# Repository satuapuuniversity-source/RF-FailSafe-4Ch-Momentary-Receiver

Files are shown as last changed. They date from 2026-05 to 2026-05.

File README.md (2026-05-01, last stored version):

This project is a smart RF receiver board made for things like quiz buzzers, remote switches, or simple automation systems.

Normally, RF receivers can have a problem:
👉 if the signal suddenly stops, the output can get “stuck” ON.
That’s bad, especially in real applications.

So I fixed that.

This board uses a small logic chip (74HC08) to make sure:
✔ the output turns ON only when a signal is actually present
✔ and turns OFF instantly when the signal is gone

So everything works clean and momentary—just like pressing a button.

Another cool thing is the RCA outputs.
They work like simple switches (dry contact), not powered outputs.

👉 That means you can safely connect this board to other systems without worrying about voltage mismatch.

Each channel also has:
💡 a small LED
🔁 a sensing loop (10k resistor)

So you can see if your external device is connected and working. Super helpful during setup.

For power, it runs on a single 18650 battery, and a boost converter keeps everything stable at 5V.
So it’s portable and reliable.

And the PCB?
Designed in KiCad with clear labels, so it’s easy to install and use, even if you're not an expert.

👉 In short:
This is a safe, reliable, no-glitch RF receiver that behaves exactly how you expect—no stuck signals, no confusion.

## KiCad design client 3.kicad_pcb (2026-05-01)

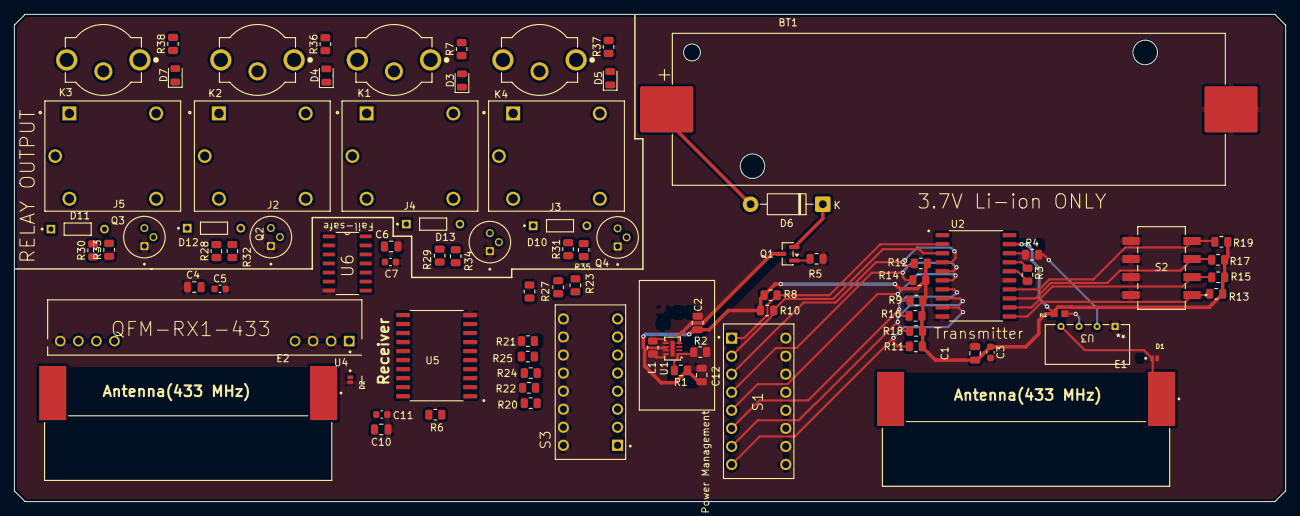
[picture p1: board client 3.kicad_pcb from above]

Board: 2 copper layers, 178.8 x 68.5 mm, 86 parts (0 on the bottom side), 67 nets.

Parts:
BT1: Battery_Cell; BatteryHolder_Keystone_1042_1x18650
C1, C4, C6, C10: 10uF; C_0805_2012Metric
C2, C12: 10u; C_0805_2012Metric
C3, C5, C7, C11: 0.1u; C_0603_1608Metric
D1, D2: PESD5V0S1UL_315; DIO_PESD5V0S1UL_315
D3, D4, D5, D7: LED; LED_0805_2012Metric
D6: 1N4007; D_DO-41_SOD81_P10.16mm_Horizontal
D10, D11, D12, D13: 1N4148; DIOAD753W49L380D172B
E1, E2: ANT-433-HESM; XDCR_ANT-433-HESM
FL1: BLM18PG121SN1D; BEADC1608X95N
J2, J3, J4, J5: RCJ-023; CUI_RCJ-023
K1, K2, K3, K4: SRD-05VDC-SL-C; RELAY_SRD-05VDC-SL-C
L1: 4.7u; R_0805_2012Metric
Q1: SI2301CDS-T1-E3; SOT-23
Q2, Q3, Q4, Q5: 2N2222A; TO127P584H533-3
R1: 976K; R_0805_2012Metric
R2: 309K; R_0805_2012Metric
R3: 1M; R_0805_2012Metric
R4, R32, R33, R34, R35: 1k; R_0805_2012Metric
R5: 100k; R_0805_2012Metric
R6: 51k; R_0805_2012Metric
R7, R8, R9, R10, R11, R12, R13, R14, R15, R16, R17, R18, R19, R20, R21, R22, R23, R24, R25, R26, R27, R28, R29, R30, R31, R36, R37, R38: 10k; R_0805_2012Metric
S1, S3: DS01C-254-L-08BE; SW_DS01C-254-L-08BE
S2: 219-4MST; SW_219-4MST
U1: MCP1640T-I/MC; DFN-8-1EP_2x3mm_P0.5mm_EP0.61x2.2mm
U2: HT12E-20SOP; SOP127P1032X264-20N
U3: QAM-TX2-433; QAM-TX2-433_RFS
U4: QFM-RX1-433; MODULE_QFM-RX1-433
U5: HT12D; SOP127P1032X264-20N
U6: 74HC08D_653; SOIC127P600X175-14N

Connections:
+5V: C1.1, C2.1, C3.1, C4.1, C5.1, C6.1, C7.1, C10.1, C11.1, C12.1, D10.K, D11.K, D12.K, D13.K, FL1.1, K1.A1, K2.A1, K3.A1, K4.A1, R1.1, R8.2, R9.2, R10.2, R11.2, R12.2, R13.2, R14.2, R15.2, R16.2, R17.2, R18.2, R19.2, R20.2, R21.2, R22.2, R23.2, R24.2, R25.2, R26.2, R27.2, R28.2, R29.2, R30.2, R31.2, U1.6 (VOUTP), U1.7 (VOUTS), U2.19 (VDD), U4.4 (SUPPLY_VOLTAGE), U4.5 (SUPPLY_VOLTAGE), U5.19 (VDD), U6.14 (VCC)
/Receiver/Relay_Ch1: R28.1, R32.1, U6.3 (1Y)
/Receiver/Relay_Ch2: R31.1, R35.1, U6.6 (2Y)
/Receiver/Relay_Ch3: R29.1, R34.1, U6.8 (3Y)
/Receiver/Relay_Ch4: R30.1, R33.1, U6.11 (4Y)
GND: BT1.2 (-), C1.2, C2.2, C3.2, C4.2, C5.2, C6.2, C7.2, C10.2, C11.2, C12.2, D1.A, D2.A, Q2.1, Q3.1, Q4.1, Q5.1, R2.2, R5.2, S1.1B, S1.2B, S1.3B, S1.4B, S1.5B, S1.6B, S1.7B, S1.8B, S2.5, S2.6, S2.7, S2.8, S3.1B, S3.2B, S3.3B, S3.4B, S3.5B, S3.6B, S3.7B, S3.8B, U1.2 (SGND), U1.3 (PGND), U1.9 (EP), U2.10 (VSS), U2.15 (~TE), U3.1 (GND), U4.2 (GROUND), U4.3 (GROUND), U4.8 (GROUND), U5.10 (VSS), U6.7 (GND)
unnamed: BT1.1 (+), D6.2 (A)
unnamed: D3.2 (A), R7.1
unnamed: D3.1 (K), J4.2, K1.NO
unnamed: D4.2 (A), R36.1
unnamed: D4.1 (K), J2.2, K2.NO
unnamed: D5.2 (A), R37.1
unnamed: D5.1 (K), J3.2, K4.NO
unnamed: D6.1 (K), Q1.2 (S)
unnamed: D7.2 (A), R38.1
unnamed: D7.1 (K), J5.2, K3.NO
unnamed: D10.A, K4.A2, Q4.3
unnamed: D11.A, K3.A2, Q3.3
unnamed: D12.A, K2.A2, Q2.3
unnamed: D13.A, K1.A2, Q5.3
unnamed: J2.1A (1), J2.1B (1), K2.COM, R36.2
unnamed: J3.1A (1), J3.1B (1), K4.COM, R37.2
unnamed: J4.1A (1), J4.1B (1), K1.COM, R7.2
unnamed: J5.1A (1), J5.1B (1), K3.COM, R38.2
unnamed: L1.1, Q1.3 (D), U1.4 (EN), U1.8 (VIN)
unnamed: Q1.1 (G), R5.1
unnamed: Q2.2, R32.2
unnamed: Q3.2, R33.2
unnamed: Q4.2, R35.2
unnamed: Q5.2, R34.2
unnamed: L1.2, U1.5 (SW)
unnamed: R1.2, R2.1, U1.1 (VFB)
unnamed: R8.1, S1.1A, U2.2 (A0)
unnamed: R10.1, S1.2A, U2.3 (A1)
unnamed: R12.1, S1.3A, U2.4 (A2)
unnamed: R14.1, S1.4A, U2.5 (A3)
unnamed: R9.1, S1.5A, U2.6 (A4)
unnamed: R16.1, S1.6A, U2.7 (A5)
unnamed: R18.1, S1.7A, U2.8 (A6)
unnamed: R11.1, S1.8A, U2.9 (A7)
unnamed: R13.1, S2.1, U2.11 (AD8)
unnamed: R15.1, S2.2, U2.12 (AD9)
unnamed: R17.1, S2.3, U2.13 (AD10)
unnamed: R19.1, S2.4, U2.14 (AD11)
unnamed: R4.1, U2.18 (DOUT)
unnamed: R3.1, U2.17 (OSC1)
unnamed: R3.2, U2.16 (OSC2)
unnamed: D1.K, E1.1, U3.4 (ANT)
unnamed: R4.2, U3.2 (IN)
unnamed: FL1.2, U3.3 (VCC)
unnamed: U4.7 (DATA_INPUT), U5.15 (DIN)
unnamed: D2.K, E2.1, U4.1 (EXTERNAL_ANTENNA)
unnamed: R20.1, S3.1A, U5.2 (A0)
unnamed: R22.1, S3.2A, U5.3 (A1)
unnamed: R24.1, S3.3A, U5.4 (A2)
unnamed: R25.1, S3.4A, U5.5 (A3)
unnamed: R21.1, S3.5A, U5.6 (A4)
unnamed: R26.1, S3.6A, U5.7 (A5)
unnamed: R27.1, S3.7A, U5.8 (A6)
unnamed: R23.1, S3.8A, U5.9 (A7)
unnamed: U5.11 (D8), U6.1 (1A)
unnamed: U5.12 (D9), U6.4 (2A)
unnamed: U5.13 (D10), U6.9 (3A)
unnamed: U5.14 (D11), U6.12 (4A)
unnamed: R6.1, U5.17 (OSC1)
unnamed: R6.2, U5.16 (OSC2)
unnamed: U5.18 (VT), U6.2 (1B), U6.5 (2B), U6.10 (3B), U6.13 (4B)
